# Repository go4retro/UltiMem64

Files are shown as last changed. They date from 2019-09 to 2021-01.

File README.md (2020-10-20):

# UltiMem64 

A 2 IC SRAM replacement for the Commodore 64 that offers all of the advantages of the VSP-fixed 64kB SRAM modules plus 2 megabytes of directly accessible RAM using a full featured memory management unit (MMU).

## Introduction

UltiMem64 replace the 2 4464 DRAM ICs on newer Commodore 64 motherboards (and can be installed in older 8-IC 4164 DRAM based motherboards using the DRAMCarrier PCB) and provides access to 2 megabytes of direct memory access (not REU access). The memory is instantly available when requested, no DMA needed.  The Color RAM IC installs in the 2114 space on motherboards containing a 2114 Color RAM and provides access to 64 kilobytes of Color memory nybbles.

## Technical Details

(*Although this information is currently correct, it may change based on developer feedback*)

The Commodore 64 64kB address space is partitioned into 16 4kB "pages", corresponding to the first nybble of a 16 bit address (the 'D' in $D0FF). The 2MB SRAM is likewise also partitioned into 4kB pages, which can then be mapped into any (or all) of the 16 slots in the MMU.

The MMU also supports the concept of a "mapping set", which means the developer can arrange up to 256 different 16 slot memory mappings, and choose any one of them at will.  Swapping out 64kB of RAM can take as little as 4 cycles (sta MAPPING_REG).

The system starts up in "hidden" mode, where the registers cannot be set or read from memory.  Reading some "magic addresses" will unhide the registers:

- $C0AA
- $C055
- $C0FF
- $C000
- $CO&lt;PAGE&gt;, where &lt;page&gt; is the high byte of the location where the registers should appear ($FF would place the registers at $ff00-)

Once the registers are visible, the are as follows:

| Register | Bit  | Note |
| --- | ---- | --- |
| BASE | 0 | MMU enabled |
| BASE+1 | 7:0  | MMU mapping "window" |
| BASE+2 | 7:0  | MMU mapping in use |
| BASE+3 | 6:0  | Color RAM 1kB mapping |
| BASE+10 to BASE+1F | 7:0  | Low bits of 16 MMU mappings (16 mappings)  |
| BASE+20 to BASE+2F | 7:0  | High bits of 16 MMU mappings (16 mappings) |

To map memory, set the mapping "window" to the set you wish to change, and then alter the data in values BASE+10 to BASE+2F.  To run the code in that mapping, set the value of the map usage register to the desired map number (0-255).

Currently, to hide the registers, simply read the magic memory locations again and set the <page> to be 0.

The MMU replaces the upper 4 bits of the 16 bit memory address with the 9 bits of data from the mapping registers, using the upper 4 bits as a 0-15 "index" into the mapping set (mapping 0 will be used for memory access in the $0XXX range, etc.).  When the MMU is off, only the first 64kB of the SRAM is visible.

Since any mapping can point to any 4kB space in the real address space, one can place the same memory bank in multiple locations in the address map (map $123C00 so it appears at $4C00 and $FC00) or other interesting combinations.

The Color RAM mapping is simpler, and is simply a 6 bit value that choose which of the 64 1kB Color RAM "pages" will be used for the Color RAM data. There is no way to set Color RAM without switching to that specific mapping, so it is best to populate/change Color RAM during video blanking periods.

## Future Directions:

- Expand SRAM to 8MB (Alliance offers an 8MB SRAM in the same footprint)
- Utilize top two bits of MMU mapping to set read/write and IRQ on write flags for any 5kB page.
- Support a way to set mapping set without unhiding all registers (like 128 does)
- Possibly support a way to support auto-incremented memory store/read.

## License
Copyright (C) 2019-20  RETRO Innovations

These files are free designs; you can redistribute them and/or modify
them under the terms of the Creative Commons Attribution-ShareAlike 
4.0 International License.

You should have received a copy of the license along with this
work. If not, see <http://creativecommons.org/licenses/by-sa/4.0/>.

These files are distributed in the hope that they will be useful,
but WITHOUT ANY WARRANTY; without even the implied warranty of
MERCHANTABILITY or FITNESS FOR A PARTICULAR PURPOSE.  See the
license for more details.

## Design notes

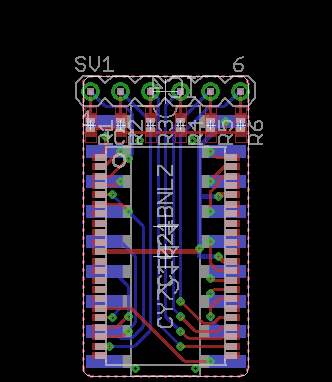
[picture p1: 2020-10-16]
pcb/UltiMem64_Color.png

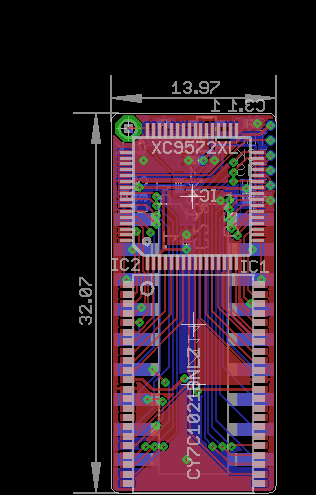
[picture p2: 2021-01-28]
pcb/UltiMEM64_Color PCB.png

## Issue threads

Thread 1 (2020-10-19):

Thoughts on memory expansion and MMU etc

gardners, 2020-10-19:
Hi Jim,

Nice project.  A couple of thoughts and ideas:

1. For the colour RAM, have you thought about having the colour RAM selection automatically change every raster line, so that you have a kind of "hardware FLI"?  You only need to use 8 of the 1K pages for this.

2. Much has been said about the upper-nybl of the colour RAM not being physically connected, and the last 24 bytes not being used, and thus might be candidate register locations. The later seems a sensible approach to me, but you will still want some kind of knock, so that routines that just fill all 4 pages of colour RAM don't cause problems.  Your four-step knock looks ok, if perhaps a little over-complex, in so far as the number of cycles required will be quite high.  Liveable, but just something worth keeping in mind.  If you are sniffing the bus, you could instead use one or more of the unintended NOP opcodes to do most of it.

Paul.

go4retro, 2020-10-19:
The Color RAM idea sounds cool, I'll consider it.

On the knock, concerning Color RAM, if I work the functionality into the 2114 SRAM replacement, I doubt I'd need the knock all the time.  Knock to turn it on, and then just leave it on (I'd assume the dev using the feature would just set the last 24 nybbles to 0, to ensure VSP code would look OK, and then switch the last 24 bytes to registers, and always use them (the design would need a flying lead to PHI0, since it'd need to know which accesses are CPU and which are VIC.  Robin Harbron asked that the design offer a way to configue a page of SRAM not currently in use, so the code could use one page for display while setting up a shadow copy for the next frame, wihtout having to wait until the end of the frame to do that.  To enable that type of features requires access to PHI0.

As for the main unit, I could use non standard NOPs, though if someones wants to support this MMU design on a 65C02 or 65C816-based upgrade, that would pose problems (existing code would fail on those newer units).  Thoughts?

gardners, 2020-10-19:
Agreed using the colour RAM 24 spare nybls for registers makes the most sense, I think.

As for the non-standard NOPs, you are right, that this won't be a solution for 65C02 or 65C816 processors, so it should be an optional mode of operation.

Meanwhile, I have an idea for another C64 add-on board, to help discover remaining VIC-II tricks if you are interested. Basically it is a cartridge that pulls DMA low, and interfaces to a host computer allowing the host computer to determine every memory access during each video frame. That is, you can say which registers get written at exactly which cycle of which raster line (and probably even do some horrible tricks with doing multiple accesses per cycle for the chips with async registers).  This would allow for rapidly exploring potential VIC-II tricks, without having to make C64 code that actually achieves that.  It would be up to the demo coders to then work out code that achieves those memory accesses in practice.

go4retro, 2020-10-20:
I am indeed interested.  What speed uC/host computer were you considering?  I know there's a RPi cart that interfaces that to the bus.

Jim

gardners, 2020-10-22:
Hi Jim,

I'd just use a cheap FPGA + USB serial interface. A MAX10 FPGA + JTAG USB serial adapter + level converters and buffers should be sufficient.  The FPGA can do the bus control, and has enough internal RAM to hold the info on every required memory access over a whole frame (~17K/21K cycles (NTSC/PAL) x (2 address bytes plus 1 data byte).  Power requirements would be low enough to be powered from the C64 expansion port.

Paul.

gardners, 2020-10-22:
... It could also double as a multipurpose cartridge emulator.

go4retro, 2020-10-23:
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
To save time, I was looking for a prebuilt module for the FPGA.  THis
one is so close, but only has 38 IO:

https://www.ebay.com/itm/STEP-MAX10-Intel-Altera-FPGA-development-board-/143318504573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

Jim

--
RETRO Innovations, Contemporary Gear for Classic Systems
www.go4retro.com
store.go4retro.com

gardners, 2020-10-23:
Going for a pre-built FPGA module to fit to a cheap adapter board would make sense, as I don't think the volume for this product would be particularly high. In that case, I would recommend going for a TE0725-03 from Trenz Electronic, who also make the MEGA65 mainboards.  I use the TE0725 in the MEGAphone and other projects, and am thus quite familiar with it. It has 104 IO available, which is more than enough.  We could copy the level converters etc from the MEGA65 main board schematic, and have a working thing pretty quickly.

Another funny approach would be to make an adapter that connects a MEGA65 to a C64 via the expansion port, and allows the same functions.

go4retro, 2020-10-24:
Dunno, that part is both overkill and also not enough for hobbyist use.  It requires a JTAG programmer, where the MAX10 board I linked has a built in programmer, so nothing else needed, and it's half the price.  With a cheap FR4 PCB with some simple level converters and this board, you're still below $50.00 in costs, whereas the other option is significantly more.  I realize it is not a huge demand board, but I think the USB programming and the half price point would allow it to be the basis for many more projects.

I think I'd rather find a way to deal with the 2 missing signals, the price point is much better.

Jim

gardners, 2020-10-24:
Understood. So, in terms of signals, you need to be able to write A0-15 and D0-7 = 24 lines. Then you need to be able to tri-state those = +1 signal. Then you probably want to monitor /BA, and be able to pull /DMA low, so +2 signals.  That still is only 27 signals. You in fact then have enough for separately tri-stating D0-7 and being able to drive them: +9 signals = 36 signals.  I guess you also want /RESET so that it can be used to reset the machine +1 = 37. Then you can monitor either /EXROM or /GAME, but not both, to use up the last pin in your 38-pin budget.

But if you are willing to consider a full custom PCB, you can use a MAX10 and get lots more spare pins.

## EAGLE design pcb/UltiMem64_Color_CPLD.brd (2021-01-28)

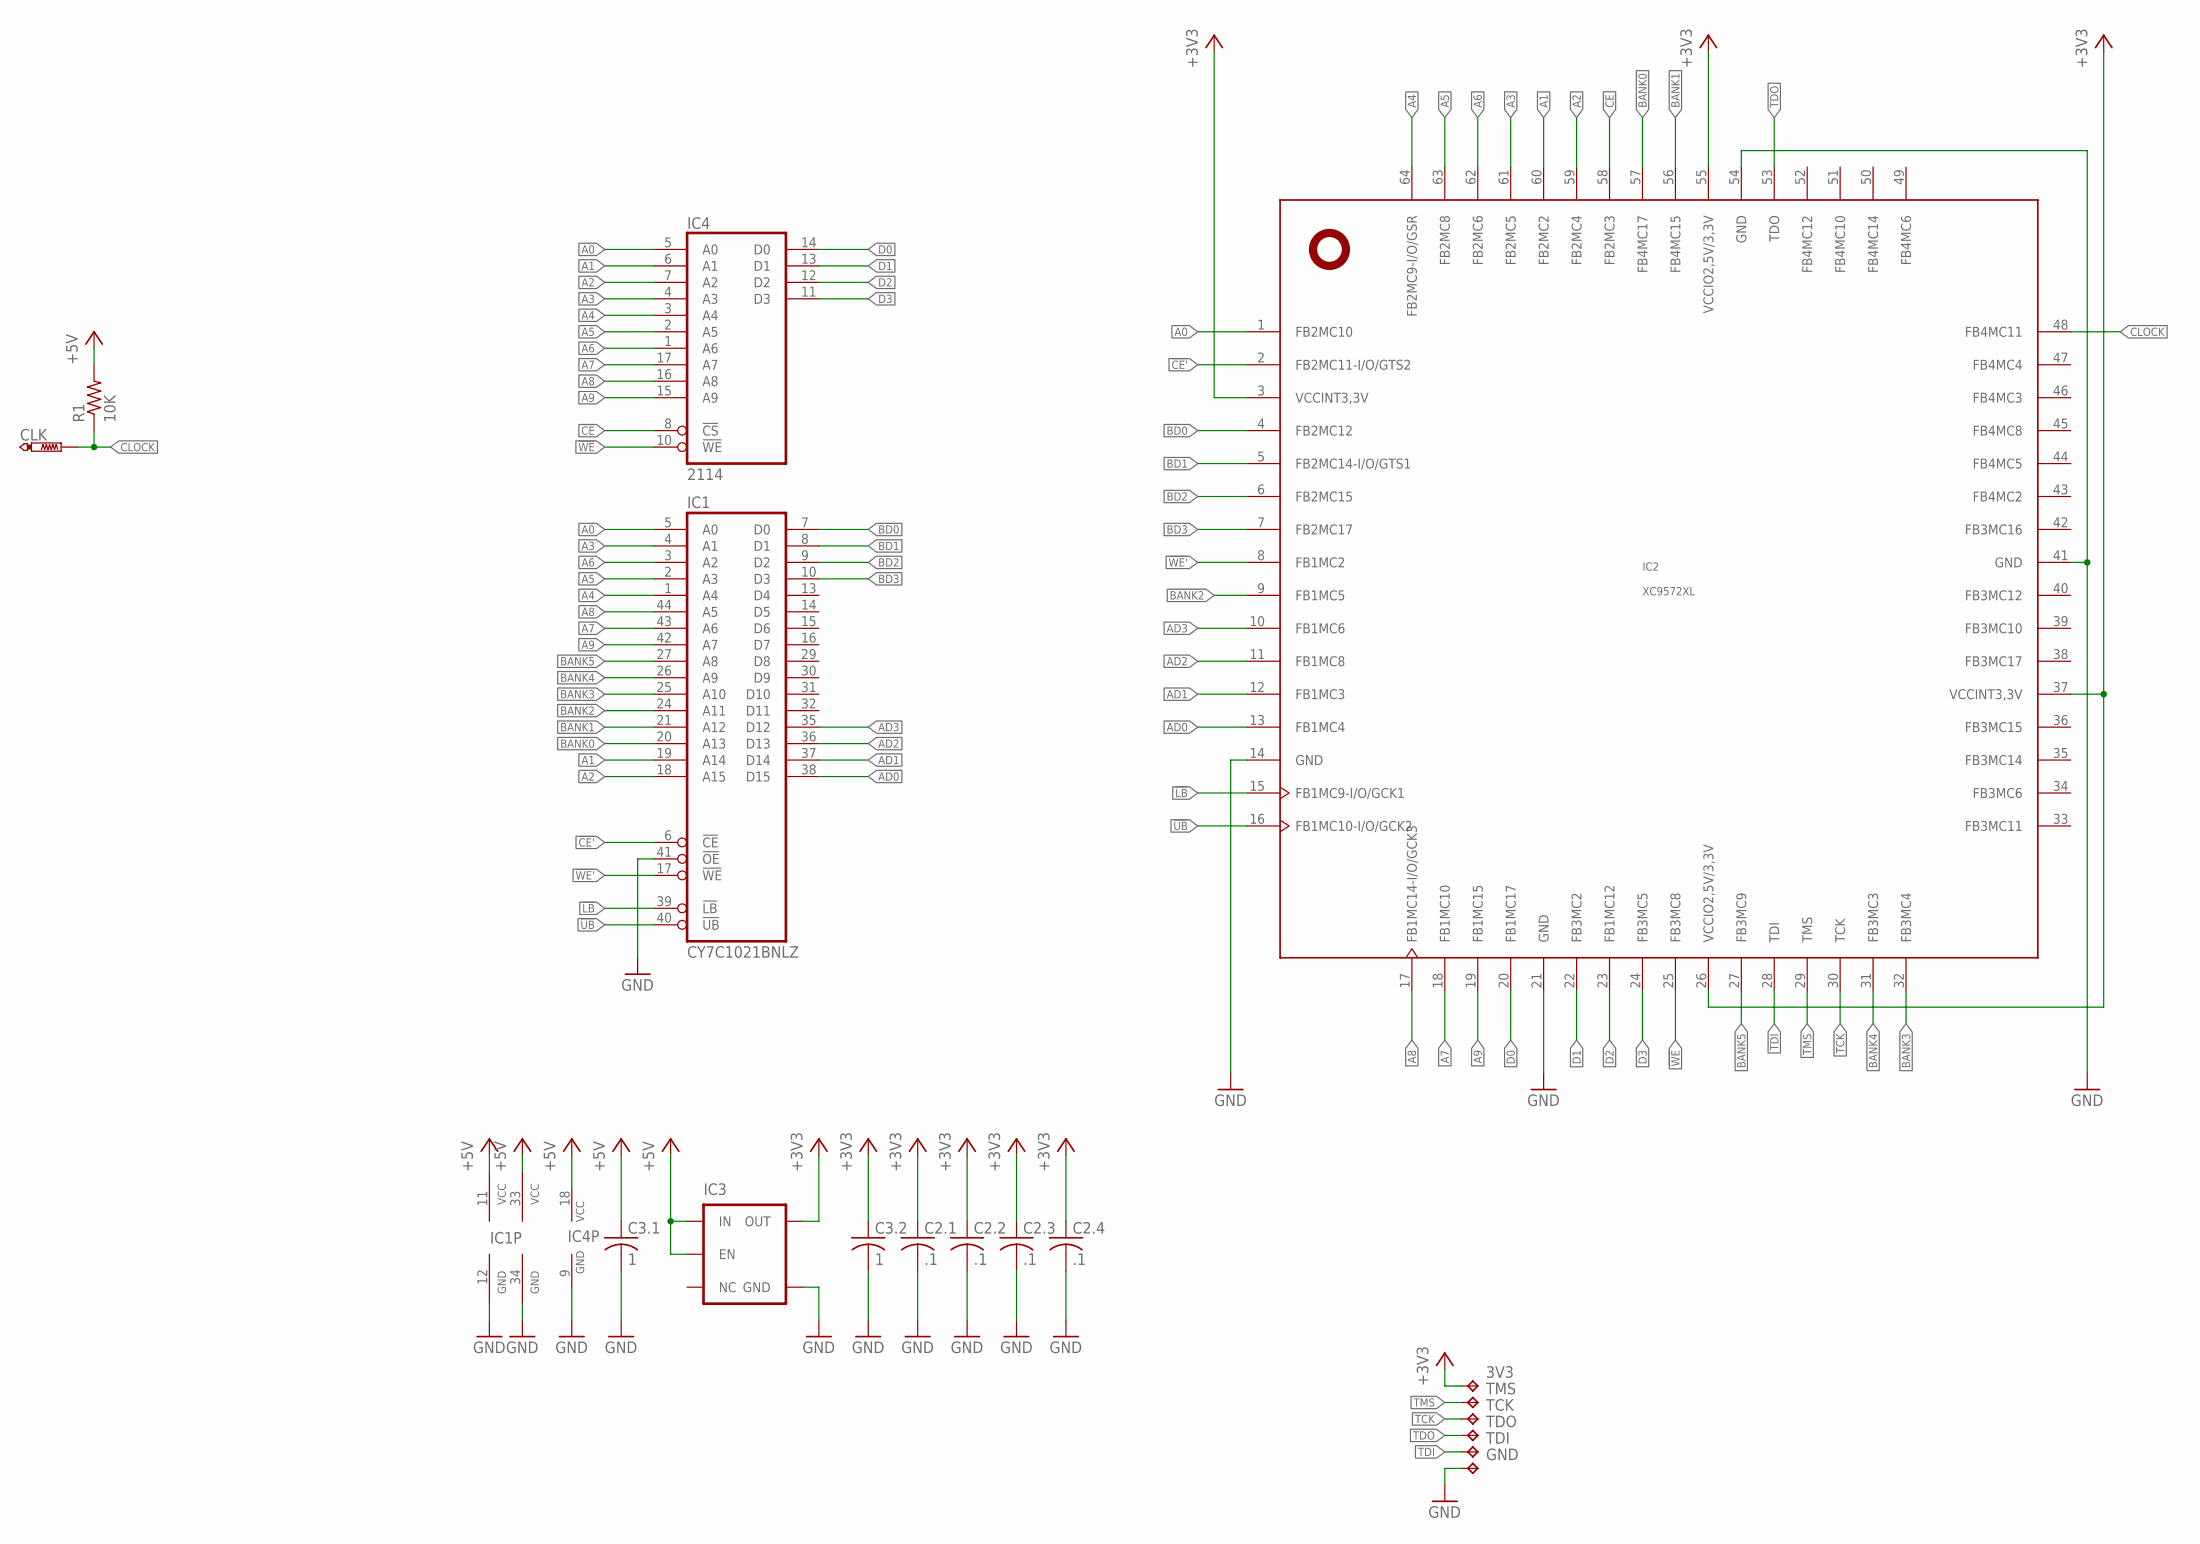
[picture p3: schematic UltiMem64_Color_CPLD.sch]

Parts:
3V3: TPTP09R; TP09R
C2.1, C2.2, C2.3, C2.4: .1; C0402
C3.1, C3.2: 1; C0402
CLK: PTR1PAD1-13; P1-13
GND: TPTP09R; TP09R
IC1: CY7C1021BNLZ; TSOP44-II
IC2: XC9572XL; VQFP64
IC3: V_REG_TPS76433SOT23-5; SOT23-5
IC4: 2114; DIL18-SMD-REVERSE
R1: 10K; R0402
TCK: TPTP09R; TP09R
TDI: TPTP09R; TP09R
TDO: TPTP09R; TP09R
TMS: TPTP09R; TP09R

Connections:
!CE: IC2.58 (FB2MC3), IC4.8 (!CS)
!CE': IC1.6 (!CE), IC2.2 (FB2MC11-I/O/GTS2)
!LB: IC1.39 (!LB), IC2.15 (FB1MC9-I/O/GCK1)
!UB: IC1.40 (!UB), IC2.16 (FB1MC10-I/O/GCK2)
!WE: IC2.25 (FB3MC8), IC4.10 (!WE)
!WE': IC1.17 (!WE), IC2.8 (FB1MC2)
+3V3: 3V3.TP, C2.1.1, C2.2.1, C2.3.1, C2.4.1, C3.2.1, IC2.3 (VCCINT3,3V), IC2.26 (VCCIO2,5V/3,3V), IC2.37 (VCCINT3,3V), IC2.55 (VCCIO2,5V/3,3V), IC3.5 (OUT)
+5V: C3.1.1, IC1.11 (VCC), IC1.33 (VCC), IC3.1 (IN), IC3.3 (EN), IC4.18 (VCC), R1.2
A0: IC1.5 (A0), IC2.1 (FB2MC10), IC4.5 (A0)
A1: IC1.19 (A14), IC2.60 (FB2MC2), IC4.6 (A1)
A2: IC1.18 (A15), IC2.59 (FB2MC4), IC4.7 (A2)
A3: IC1.4 (A1), IC2.61 (FB2MC5), IC4.4 (A3)
A4: IC1.1 (A4), IC2.64 (FB2MC9-I/O/GSR), IC4.3 (A4)
A5: IC1.2 (A3), IC2.63 (FB2MC8), IC4.2 (A5)
A6: IC1.3 (A2), IC2.62 (FB2MC6), IC4.1 (A6)
A7: IC1.43 (A6), IC2.18 (FB1MC10), IC4.17 (A7)
A8: IC1.44 (A5), IC2.17 (FB1MC14-I/O/GCK3), IC4.16 (A8)
A9: IC1.42 (A7), IC2.19 (FB1MC15), IC4.15 (A9)
AD0: IC1.38 (D15), IC2.13 (FB1MC4)
AD1: IC1.37 (D14), IC2.12 (FB1MC3)
AD2: IC1.36 (D13), IC2.11 (FB1MC8)
AD3: IC1.35 (D12), IC2.10 (FB1MC6)
BANK0: IC1.20 (A13), IC2.57 (FB4MC17)
BANK1: IC1.21 (A12), IC2.56 (FB4MC15)
BANK2: IC1.24 (A11), IC2.9 (FB1MC5)
BANK3: IC1.25 (A10), IC2.32 (FB3MC4)
BANK4: IC1.26 (A9), IC2.31 (FB3MC3)
BANK5: IC1.27 (A8), IC2.27 (FB3MC9)
BD0: IC1.7 (D0), IC2.4 (FB2MC12)
BD1: IC1.8 (D1), IC2.5 (FB2MC14-I/O/GTS1)
BD2: IC1.9 (D2), IC2.6 (FB2MC15)
BD3: IC1.10 (D3), IC2.7 (FB2MC17)
CLOCK: CLK.TP, IC2.48 (FB4MC11), R1.1
D0: IC2.20 (FB1MC17), IC4.14 (D0)
D1: IC2.22 (FB3MC2), IC4.13 (D1)
D2: IC2.23 (FB1MC12), IC4.12 (D2)
D3: IC2.24 (FB3MC5), IC4.11 (D3)
GND: C2.1.2, C2.2.2, C2.3.2, C2.4.2, C3.1.2, C3.2.2, GND.TP, IC1.12 (GND), IC1.34 (GND), IC1.41 (!OE), IC2.14 (GND), IC2.21 (GND), IC2.41 (GND), IC2.54 (GND), IC3.2 (GND), IC4.9 (GND)
TCK: IC2.30 (TCK), TCK.TP
TDI: IC2.28 (TDI), TDI.TP
TDO: IC2.53 (TDO), TDO.TP
TMS: IC2.29 (TMS), TMS.TP

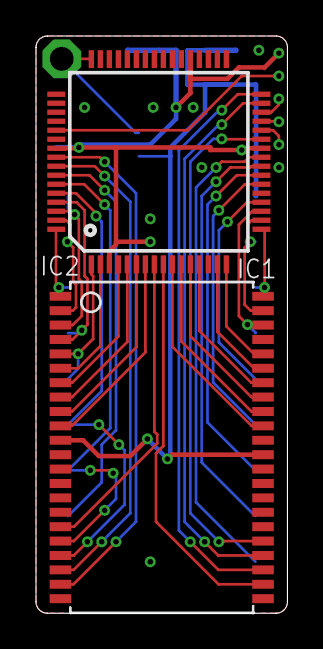
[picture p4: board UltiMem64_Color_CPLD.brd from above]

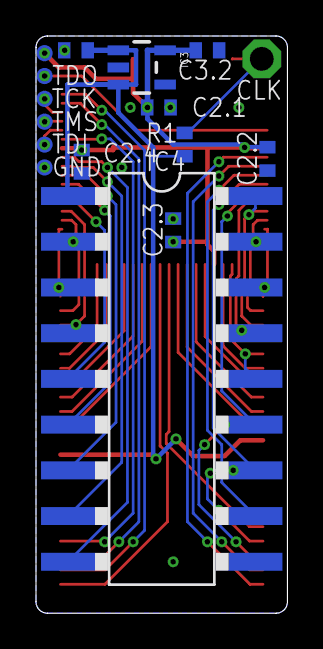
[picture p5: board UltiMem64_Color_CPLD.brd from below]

Board: 2 copper layers, 14.0 x 32.1 mm, 18 parts (15 on the bottom side), 42 nets.

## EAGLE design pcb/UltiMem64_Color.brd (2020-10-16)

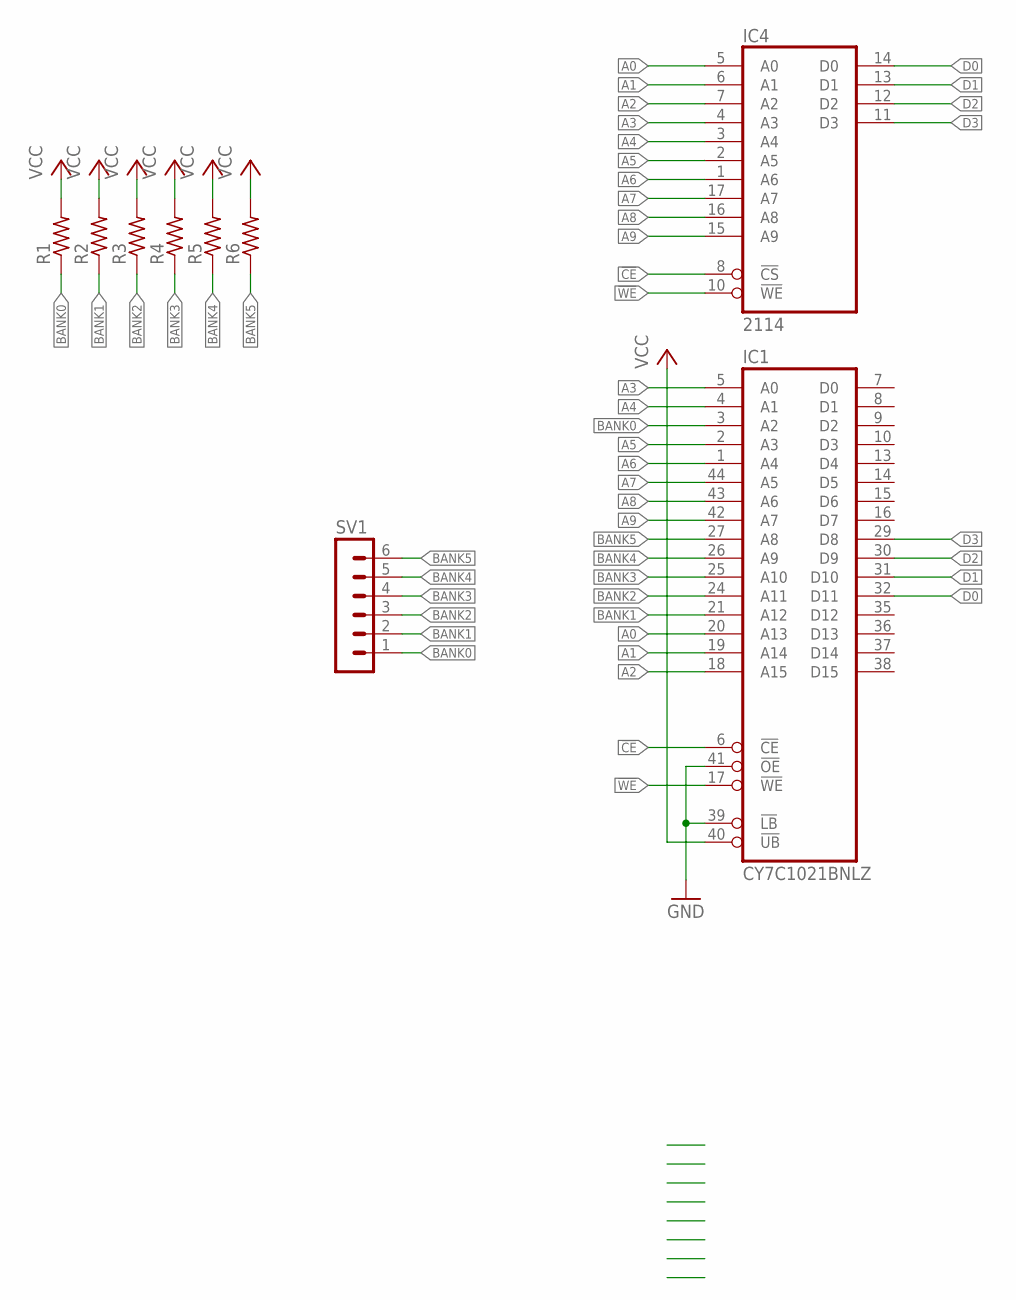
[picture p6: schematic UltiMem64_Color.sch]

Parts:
IC1: CY7C1021BNLZ; TSOP44-II
IC4: 2114; DIL18-SMD-REVERSE
R1, R2, R3, R4, R5, R6: R-US_R0402; R0402
SV1: MA06-1

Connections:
!CE: IC1.6 (!CE), IC4.8 (!CS)
!WE: IC1.17 (!WE), IC4.10 (!WE)
A0: IC1.20 (A13), IC4.5 (A0)
A1: IC1.19 (A14), IC4.6 (A1)
A2: IC1.18 (A15), IC4.7 (A2)
A3: IC1.5 (A0), IC4.4 (A3)
A4: IC1.4 (A1), IC4.3 (A4)
A5: IC1.2 (A3), IC4.2 (A5)
A6: IC1.1 (A4), IC4.1 (A6)
A7: IC1.44 (A5), IC4.17 (A7)
A8: IC1.43 (A6), IC4.16 (A8)
A9: IC1.42 (A7), IC4.15 (A9)
BANK0: IC1.3 (A2), R1.1, SV1.1
BANK1: IC1.21 (A12), R2.1, SV1.2
BANK2: IC1.24 (A11), R3.1, SV1.3
BANK3: IC1.25 (A10), R4.1, SV1.4
BANK4: IC1.26 (A9), R5.1, SV1.5
BANK5: IC1.27 (A8), R6.1, SV1.6
D0: IC1.32 (D11), IC4.14 (D0)
D1: IC1.31 (D10), IC4.13 (D1)
D2: IC1.30 (D9), IC4.12 (D2)
D3: IC1.29 (D8), IC4.11 (D3)
GND: IC1.12 (GND), IC1.34 (GND), IC1.39 (!LB), IC1.41 (!OE), IC4.9 (GND)
VCC: IC1.11 (VCC), IC1.33 (VCC), IC1.40 (!UB), IC4.18 (VCC), R1.2, R2.2, R3.2, R4.2, R5.2, R6.2

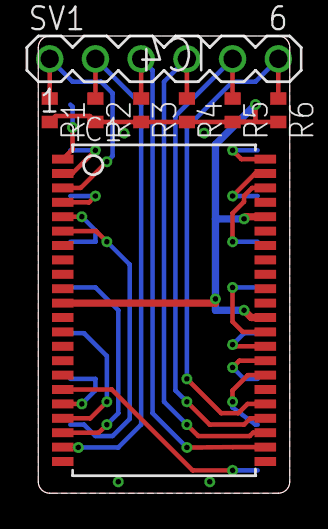
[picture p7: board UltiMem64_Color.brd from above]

Board: 2 copper layers, 14.0 x 25.4 mm, 9 parts (0 on the bottom side), 24 nets.

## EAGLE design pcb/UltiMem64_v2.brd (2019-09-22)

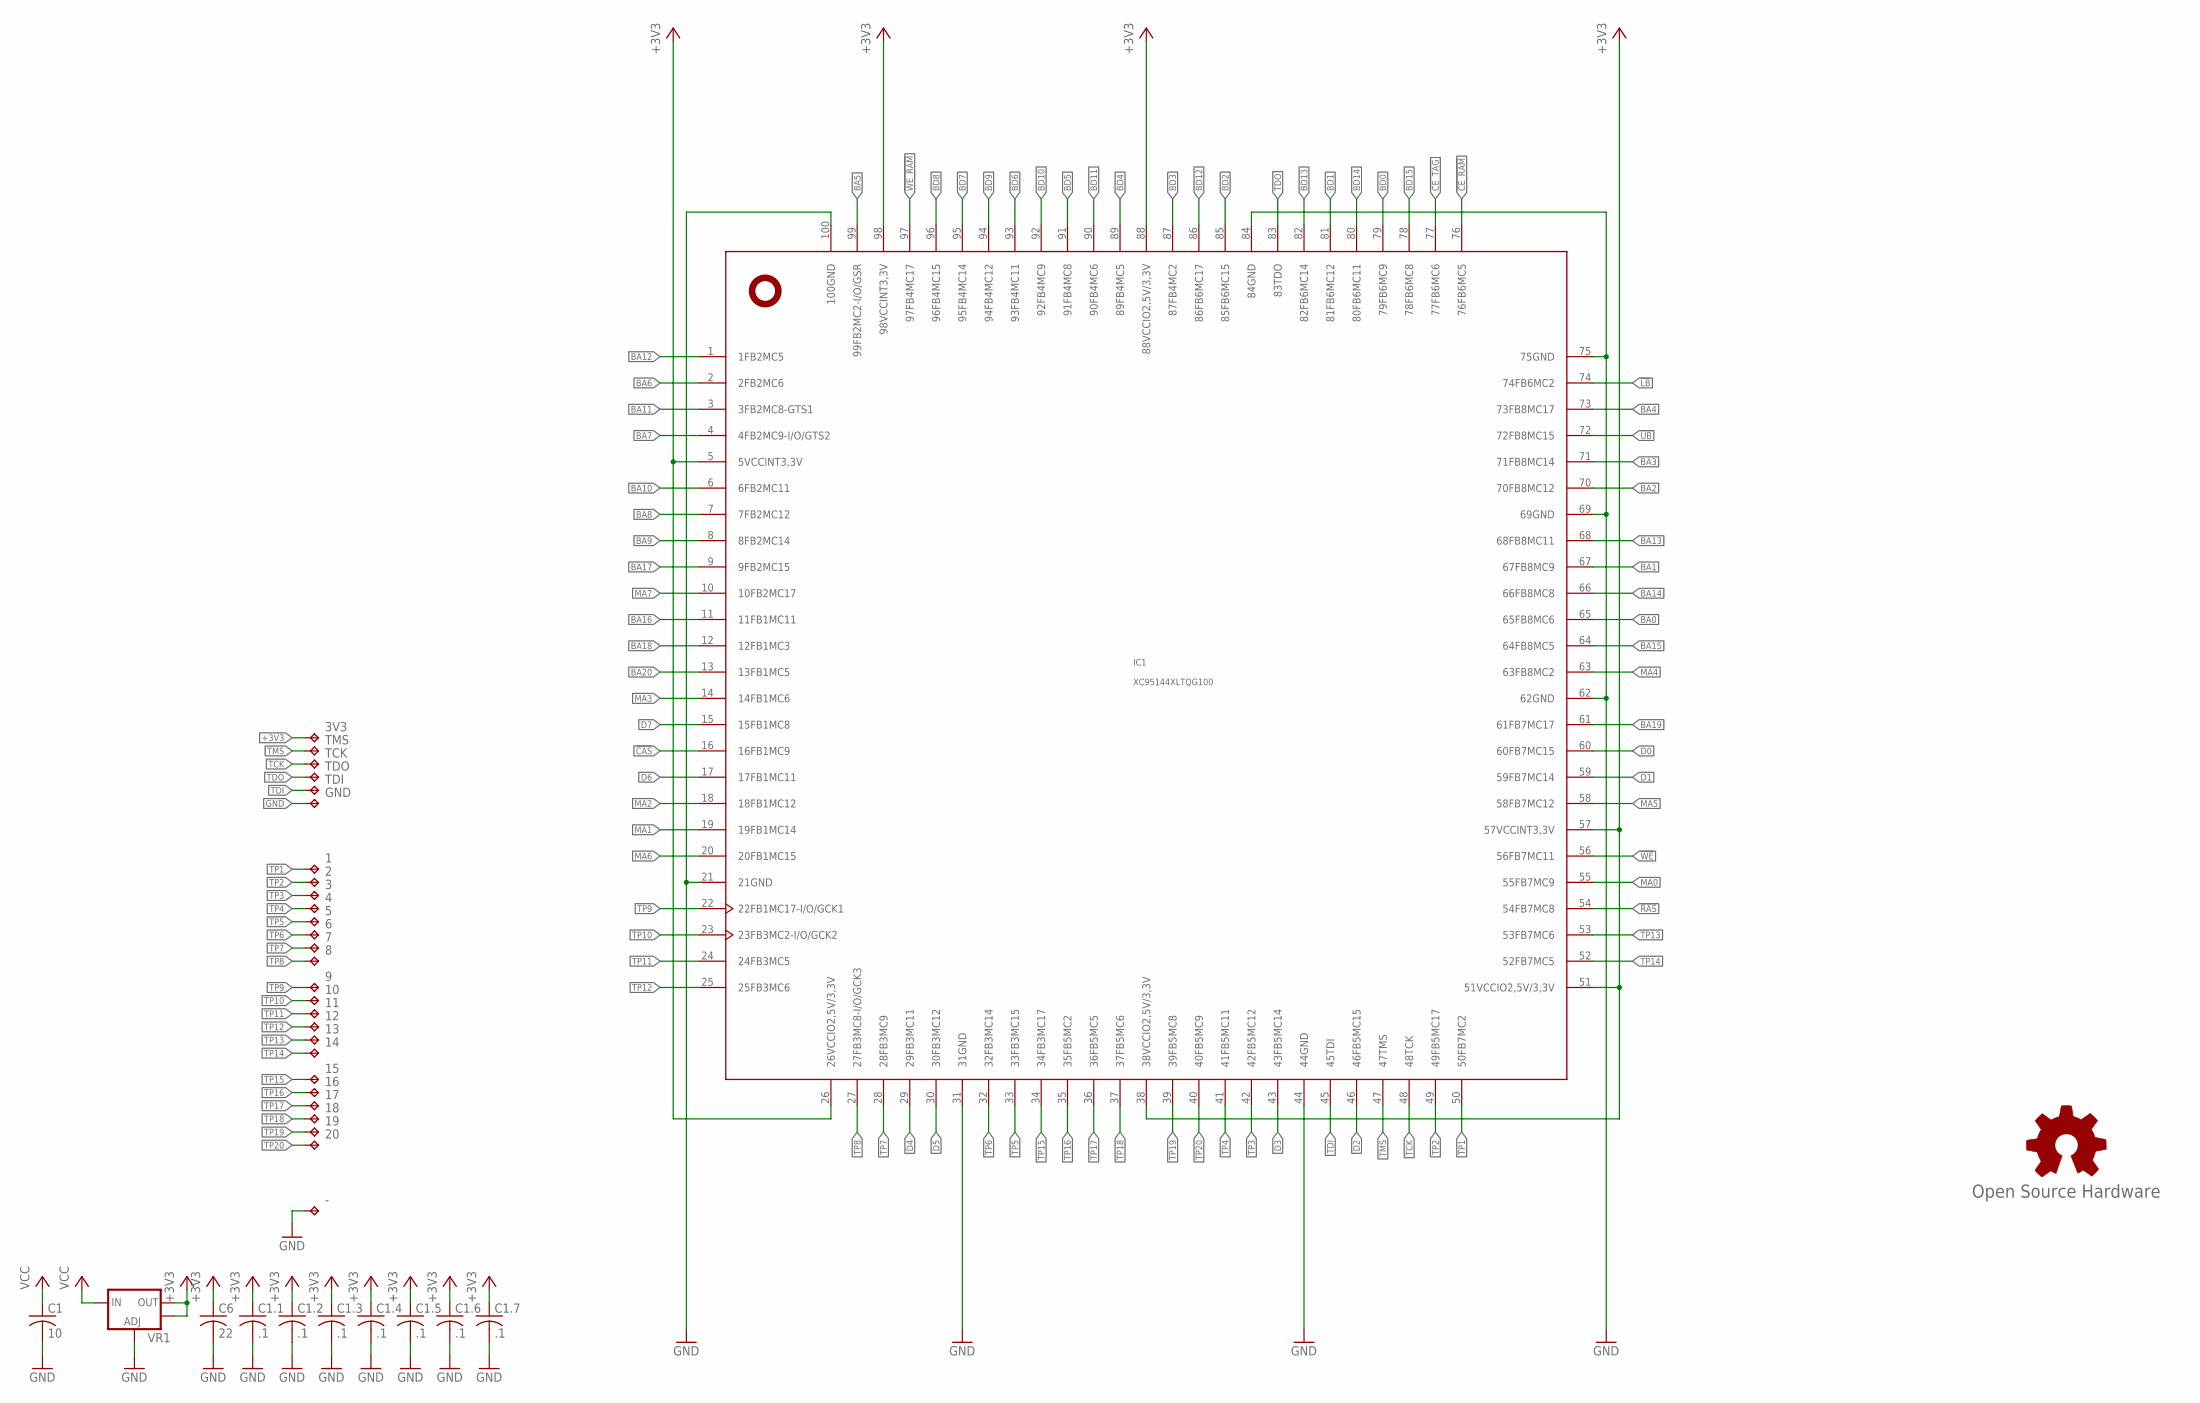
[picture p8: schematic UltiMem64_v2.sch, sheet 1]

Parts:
1, 2, 3, 4, 5, 6, 7, 8, 9, 10, 11, 12, 13, 14: TPPAD1-13; P1-13
3V3: TPTP09R; TP09R
15, 16, 17, 18, 19, 20: TPTP08R; TP08R
-: TPPAD1-13; P1-13
C1: 10; C0805
C1.1, C1.2, C1.3, C1.4, C1.5, C1.6, C1.7: .1; C0402
C6: 22; C0805
GND: TPTP10R; TP10R
GOLD_ORB_SM1: Open Source Hardware; OSHW_5MM
IC1: XC95144XLTQG100; TQFP100
TCK: TPTP09R; TP09R
TDI: TPTP09R; TP09R
TDO: TPTP09R; TP09R
TMS: TPTP09R; TP09R
VR1: V_REG_LM1117SOT223; SOT223

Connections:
!CAS: IC1.16 (16FB1MC9); also elsewhere on the board
!CE_RAM: IC1.76 (76FB6MC5); also elsewhere on the board
!CE_TAG: IC1.77 (77FB6MC6); also elsewhere on the board
!LB: IC1.74 (74FB6MC2); also elsewhere on the board
!RAS: IC1.54 (54FB7MC8); also elsewhere on the board
!UB: IC1.72 (72FB8MC15); also elsewhere on the board
!WE: IC1.56 (56FB7MC11); also elsewhere on the board
!WE_RAM: IC1.97 (97FB4MC17); also elsewhere on the board
+3V3: 3V3.TP, C1.1.1, C1.2.1, C1.3.1, C1.4.1, C1.5.1, C1.6.1, C1.7.1, C6.1, IC1.5 (5VCCINT3,3V), IC1.26 (26VCCIO2,5V/3,3V), IC1.38 (38VCCIO2,5V/3,3V), IC1.51 (51VCCIO2,5V/3,3V), IC1.57 (57VCCINT3,3V), IC1.88 (88VCCIO2,5V/3,3V), IC1.98 (98VCCINT3,3V), VR1.2 (OUT), VR1.4 (OUT); also elsewhere on the board
BA0: IC1.65 (65FB8MC6); also elsewhere on the board
BA1: IC1.67 (67FB8MC9); also elsewhere on the board
BA2: IC1.70 (70FB8MC12); also elsewhere on the board
BA3: IC1.71 (71FB8MC14); also elsewhere on the board
BA4: IC1.73 (73FB8MC17); also elsewhere on the board
BA5: IC1.99 (99FB2MC2-I/O/GSR); also elsewhere on the board
BA6: IC1.2 (2FB2MC6); also elsewhere on the board
BA7: IC1.4 (4FB2MC9-I/O/GTS2); also elsewhere on the board
BA8: IC1.7 (7FB2MC12); also elsewhere on the board
BA9: IC1.8 (8FB2MC14); also elsewhere on the board
BA10: IC1.6 (6FB2MC11); also elsewhere on the board
BA11: IC1.3 (3FB2MC8-GTS1); also elsewhere on the board
BA12: IC1.1 (1FB2MC5); also elsewhere on the board
BA13: IC1.68 (68FB8MC11); also elsewhere on the board
BA14: IC1.66 (66FB8MC8); also elsewhere on the board
BA15: IC1.64 (64FB8MC5); also elsewhere on the board
BA16: IC1.11 (11FB1MC11); also elsewhere on the board
BA17: IC1.9 (9FB2MC15); also elsewhere on the board
BA18: IC1.12 (12FB1MC3); also elsewhere on the board
BA19: IC1.61 (61FB7MC17); also elsewhere on the board
BA20: IC1.13 (13FB1MC5); also elsewhere on the board
BD0: IC1.79 (79FB6MC9); also elsewhere on the board
BD1: IC1.81 (81FB6MC12); also elsewhere on the board
BD2: IC1.85 (85FB6MC15); also elsewhere on the board
BD3: IC1.87 (87FB4MC2); also elsewhere on the board
BD4: IC1.89 (89FB4MC5); also elsewhere on the board
BD5: IC1.91 (91FB4MC8); also elsewhere on the board
BD6: IC1.93 (93FB4MC11); also elsewhere on the board
BD7: IC1.95 (95FB4MC14); also elsewhere on the board
BD8: IC1.96 (96FB4MC15); also elsewhere on the board
BD9: IC1.94 (94FB4MC12); also elsewhere on the board
BD10: IC1.92 (92FB4MC9); also elsewhere on the board
BD11: IC1.90 (90FB4MC6); also elsewhere on the board
BD12: IC1.86 (86FB6MC17); also elsewhere on the board
BD13: IC1.82 (82FB6MC14); also elsewhere on the board
BD14: IC1.80 (80FB6MC11); also elsewhere on the board
BD15: IC1.78 (78FB6MC8); also elsewhere on the board
D0: IC1.60 (60FB7MC15); also elsewhere on the board
D1: IC1.59 (59FB7MC14); also elsewhere on the board
D2: IC1.46 (46FB5MC15); also elsewhere on the board
D3: IC1.43 (43FB5MC14); also elsewhere on the board
D4: IC1.29 (29FB3MC11); also elsewhere on the board
D5: IC1.30 (30FB3MC12); also elsewhere on the board
D6: IC1.17 (17FB1MC11); also elsewhere on the board
D7: IC1.15 (15FB1MC8); also elsewhere on the board
GND: -.TP, C1.2, C1.1.2, C1.2.2, C1.3.2, C1.4.2, C1.5.2, C1.6.2, C1.7.2, C6.2, GND.TP, IC1.21 (21GND), IC1.31 (31GND), IC1.44 (44GND), IC1.62 (62GND), IC1.69 (69GND), IC1.75 (75GND), IC1.84 (84GND), IC1.100 (100GND), VR1.1 (ADJ); also elsewhere on the board
MA0: IC1.55 (55FB7MC9); also elsewhere on the board
MA1: IC1.19 (19FB1MC14); also elsewhere on the board
MA2: IC1.18 (18FB1MC12); also elsewhere on the board
MA3: IC1.14 (14FB1MC6); also elsewhere on the board
MA4: IC1.63 (63FB8MC2); also elsewhere on the board
MA5: IC1.58 (58FB7MC12); also elsewhere on the board
MA6: IC1.20 (20FB1MC15); also elsewhere on the board
MA7: IC1.10 (10FB2MC17); also elsewhere on the board
TCK: IC1.48 (48TCK), TCK.TP
TDI: IC1.45 (45TDI), TDI.TP
TDO: IC1.83 (83TDO), TDO.TP
TMS: IC1.47 (47TMS), TMS.TP
TP1: 1.TP, IC1.50 (50FB7MC2)
TP2: 2.TP, IC1.49 (49FB5MC17)
TP3: 3.TP, IC1.42 (42FB5MC12)
TP4: 4.TP, IC1.41 (41FB5MC11)
TP5: 5.TP, IC1.33 (33FB3MC15)
TP6: 6.TP, IC1.32 (32FB3MC14)
TP7: 7.TP, IC1.28 (28FB3MC9)
TP8: 8.TP, IC1.27 (27FB3MC8-I/O/GCK3)
TP9: 9.TP, IC1.22 (22FB1MC17-I/O/GCK1)
TP10: 10.TP, IC1.23 (23FB3MC2-I/O/GCK2)
TP11: 11.TP, IC1.24 (24FB3MC5)
TP12: 12.TP, IC1.25 (25FB3MC6)
TP13: 13.TP, IC1.53 (53FB7MC6)
TP14: 14.TP, IC1.52 (52FB7MC5)
TP15: 15.TP, IC1.34 (34FB3MC17)
TP16: 16.TP, IC1.35 (35FB5MC2)
TP17: 17.TP, IC1.36 (36FB5MC5)
TP18: 18.TP, IC1.37 (37FB5MC6)
TP19: 19.TP, IC1.39 (39FB5MC8)
TP20: 20.TP, IC1.40 (40FB5MC9)
VCC: C1.1, VR1.3 (IN); also elsewhere on the board

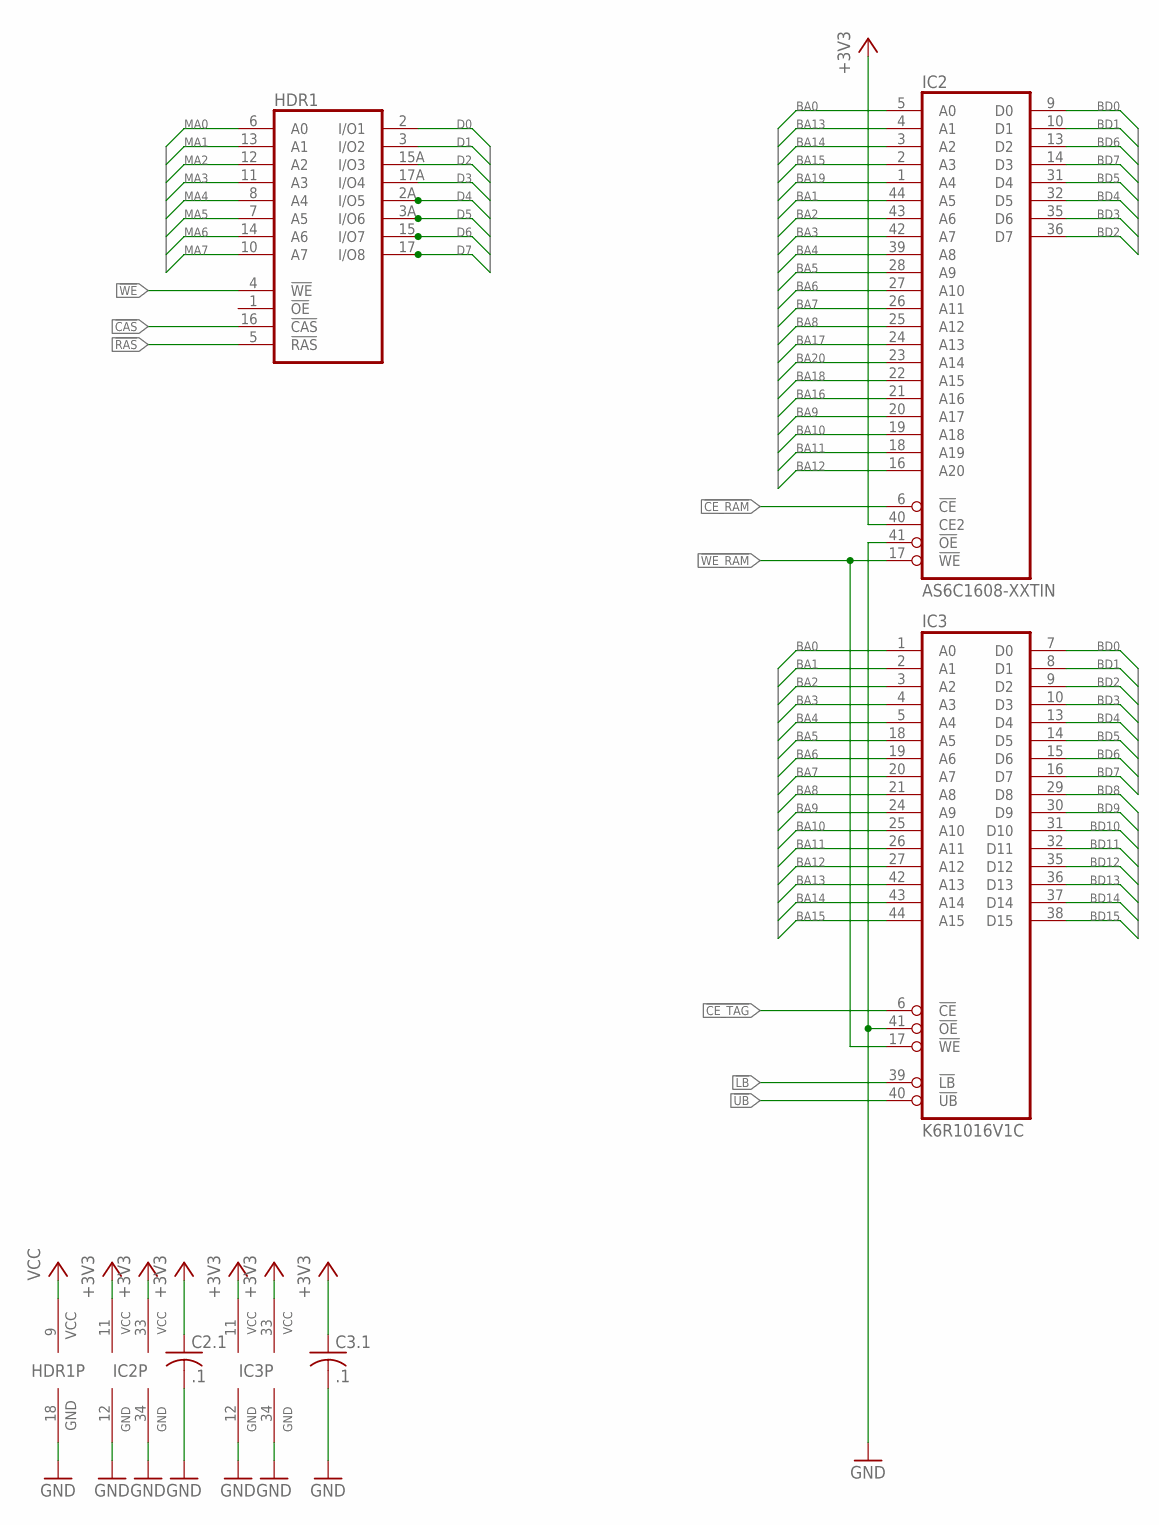
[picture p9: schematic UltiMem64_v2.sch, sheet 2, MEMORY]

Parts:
C2.1, C3.1: .1; C0402
HDR1: 2X41464C-HDR; 2XDIL18_REV
IC2: AS6C1608-XXTIN; TSOP44-II
IC3: K6R1016V1C; SOJ44/4

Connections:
!CAS: HDR1.16 (!CAS); also elsewhere on the board
!CE_RAM: IC2.6 (!CE); also elsewhere on the board
!CE_TAG: IC3.6 (!CE); also elsewhere on the board
!LB: IC3.39 (!LB); also elsewhere on the board
!RAS: HDR1.5 (!RAS); also elsewhere on the board
!UB: IC3.40 (!UB); also elsewhere on the board
!WE: HDR1.4 (!WE); also elsewhere on the board
!WE_RAM: IC2.17 (!WE), IC3.17 (!WE); also elsewhere on the board
+3V3: C2.1.1, C3.1.1, IC2.11 (VCC), IC2.33 (VCC), IC2.40 (CE2), IC3.11 (VCC), IC3.33 (VCC); also elsewhere on the board
BA0: IC2.5 (A0), IC3.1 (A0); also elsewhere on the board
BA1: IC2.44 (A5), IC3.2 (A1); also elsewhere on the board
BA2: IC2.43 (A6), IC3.3 (A2); also elsewhere on the board
BA3: IC2.42 (A7), IC3.4 (A3); also elsewhere on the board
BA4: IC2.39 (A8), IC3.5 (A4); also elsewhere on the board
BA5: IC2.28 (A9), IC3.18 (A5); also elsewhere on the board
BA6: IC2.27 (A10), IC3.19 (A6); also elsewhere on the board
BA7: IC2.26 (A11), IC3.20 (A7); also elsewhere on the board
BA8: IC2.25 (A12), IC3.21 (A8); also elsewhere on the board
BA9: IC2.20 (A17), IC3.24 (A9); also elsewhere on the board
BA10: IC2.19 (A18), IC3.25 (A10); also elsewhere on the board
BA11: IC2.18 (A19), IC3.26 (A11); also elsewhere on the board
BA12: IC2.16 (A20), IC3.27 (A12); also elsewhere on the board
BA13: IC2.4 (A1), IC3.42 (A13); also elsewhere on the board
BA14: IC2.3 (A2), IC3.43 (A14); also elsewhere on the board
BA15: IC2.2 (A3), IC3.44 (A15); also elsewhere on the board
BA16: IC2.21 (A16); also elsewhere on the board
BA17: IC2.24 (A13); also elsewhere on the board
BA18: IC2.22 (A15); also elsewhere on the board
BA19: IC2.1 (A4); also elsewhere on the board
BA20: IC2.23 (A14); also elsewhere on the board
BD0: IC2.9 (D0), IC3.7 (D0); also elsewhere on the board
BD1: IC2.10 (D1), IC3.8 (D1); also elsewhere on the board
BD2: IC2.36 (D7), IC3.9 (D2); also elsewhere on the board
BD3: IC2.35 (D6), IC3.10 (D3); also elsewhere on the board
BD4: IC2.32 (D5), IC3.13 (D4); also elsewhere on the board
BD5: IC2.31 (D4), IC3.14 (D5); also elsewhere on the board
BD6: IC2.13 (D2), IC3.15 (D6); also elsewhere on the board
BD7: IC2.14 (D3), IC3.16 (D7); also elsewhere on the board
BD8: IC3.29 (D8); also elsewhere on the board
BD9: IC3.30 (D9); also elsewhere on the board
BD10: IC3.31 (D10); also elsewhere on the board
BD11: IC3.32 (D11); also elsewhere on the board
BD12: IC3.35 (D12); also elsewhere on the board
BD13: IC3.36 (D13); also elsewhere on the board
BD14: IC3.37 (D14); also elsewhere on the board
BD15: IC3.38 (D15); also elsewhere on the board
D0: HDR1.2 (I/O1); also elsewhere on the board
D1: HDR1.3 (I/O2); also elsewhere on the board
D2: HDR1.15A (I/O3); also elsewhere on the board
D3: HDR1.17A (I/O4); also elsewhere on the board
D4: HDR1.2A (I/O5); also elsewhere on the board
D5: HDR1.3A (I/O6); also elsewhere on the board
D6: HDR1.15 (I/O7); also elsewhere on the board
D7: HDR1.17 (I/O8); also elsewhere on the board
GND: C2.1.2, C3.1.2, HDR1.18 (GND), IC2.12 (GND), IC2.34 (GND), IC2.41 (!OE), IC3.12 (GND), IC3.34 (GND), IC3.41 (!OE); also elsewhere on the board
MA0: HDR1.6 (A0); also elsewhere on the board
MA1: HDR1.13 (A1); also elsewhere on the board
MA2: HDR1.12 (A2); also elsewhere on the board
MA3: HDR1.11 (A3); also elsewhere on the board
MA4: HDR1.8 (A4); also elsewhere on the board
MA5: HDR1.7 (A5); also elsewhere on the board
MA6: HDR1.14 (A6); also elsewhere on the board
MA7: HDR1.10 (A7); also elsewhere on the board
VCC: HDR1.9 (VCC); also elsewhere on the board

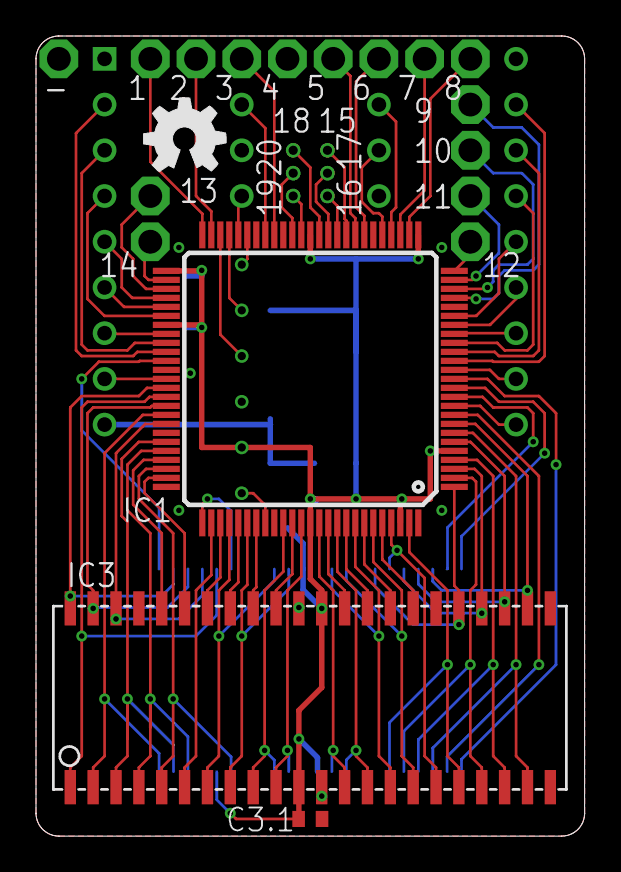
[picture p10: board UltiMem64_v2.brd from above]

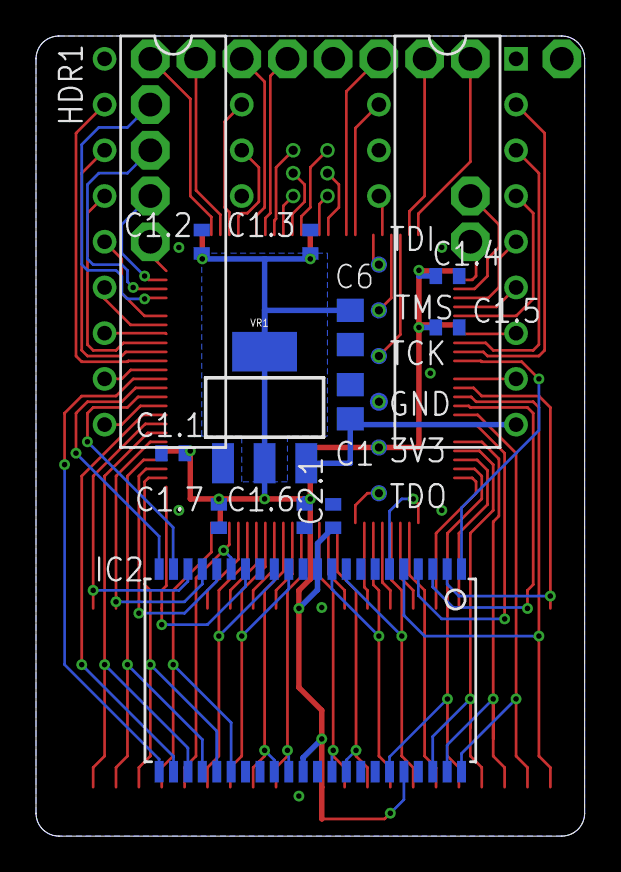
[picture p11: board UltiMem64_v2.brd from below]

Board: 2 copper layers, 30.5 x 44.5 mm, 44 parts (18 on the bottom side), 88 nets.

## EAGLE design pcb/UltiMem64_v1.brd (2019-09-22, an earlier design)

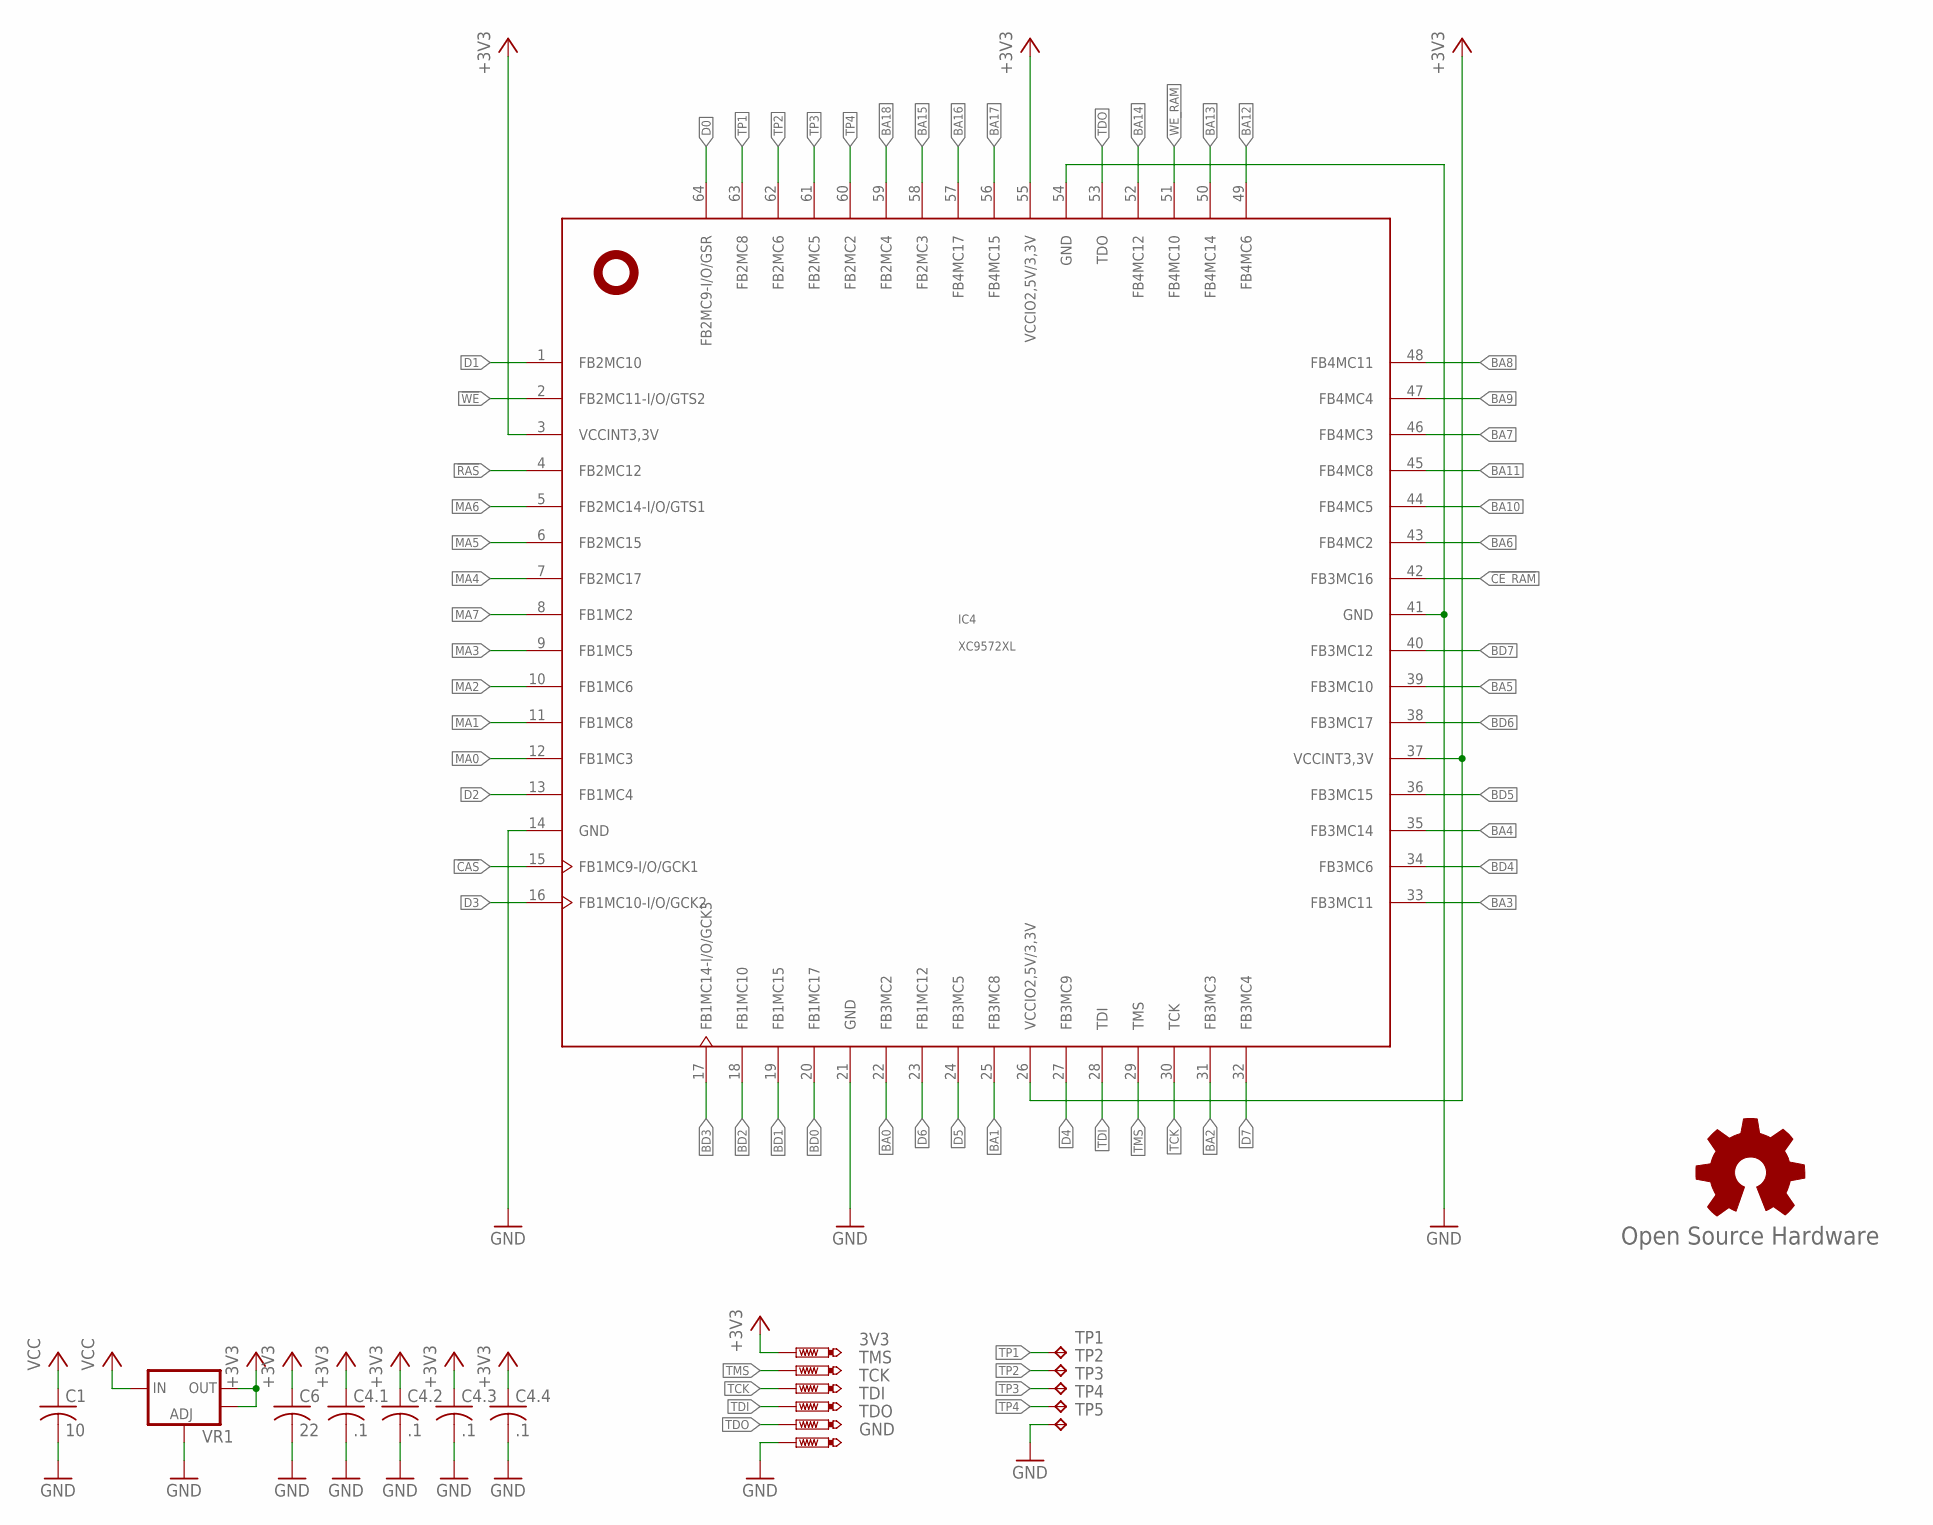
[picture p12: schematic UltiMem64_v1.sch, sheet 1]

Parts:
3V3: PTR1TP08R; TP08R
C1: 10; C0805
C4.1, C4.2, C4.3, C4.4: .1; C0402
C6: 22; C0805
GND: PTR1TP08R; TP08R
GOLD_ORB_SM1: Open Source Hardware; OSHW_5MM
IC4: XC9572XL; VQFP64
TCK: PTR1TP08R; TP08R
TDI: PTR1TP08R; TP08R
TDO: PTR1TP08R; TP08R
TMS: PTR1TP08R; TP08R
TP1, TP2, TP3, TP4, TP5: TPPAD1-13; P1-13
VR1: V_REG_LM1117SOT223; SOT223

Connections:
!CAS: IC4.15 (FB1MC9-I/O/GCK1); also elsewhere on the board
!CE_RAM: IC4.42 (FB3MC16); also elsewhere on the board
!RAS: IC4.4 (FB2MC12); also elsewhere on the board
!WE: IC4.2 (FB2MC11-I/O/GTS2); also elsewhere on the board
!WE_RAM: IC4.51 (FB4MC10); also elsewhere on the board
+3V3: 3V3.TP, C4.1.1, C4.2.1, C4.3.1, C4.4.1, C6.1, IC4.3 (VCCINT3,3V), IC4.26 (VCCIO2,5V/3,3V), IC4.37 (VCCINT3,3V), IC4.55 (VCCIO2,5V/3,3V), VR1.2 (OUT), VR1.4 (OUT)
BA0: IC4.22 (FB3MC2); also elsewhere on the board
BA1: IC4.25 (FB3MC8); also elsewhere on the board
BA2: IC4.31 (FB3MC3); also elsewhere on the board
BA3: IC4.33 (FB3MC11); also elsewhere on the board
BA4: IC4.35 (FB3MC14); also elsewhere on the board
BA5: IC4.39 (FB3MC10); also elsewhere on the board
BA6: IC4.43 (FB4MC2); also elsewhere on the board
BA7: IC4.46 (FB4MC3); also elsewhere on the board
BA8: IC4.48 (FB4MC11); also elsewhere on the board
BA9: IC4.47 (FB4MC4); also elsewhere on the board
BA10: IC4.44 (FB4MC5); also elsewhere on the board
BA11: IC4.45 (FB4MC8); also elsewhere on the board
BA12: IC4.49 (FB4MC6); also elsewhere on the board
BA13: IC4.50 (FB4MC14); also elsewhere on the board
BA14: IC4.52 (FB4MC12); also elsewhere on the board
BA15: IC4.58 (FB2MC3); also elsewhere on the board
BA16: IC4.57 (FB4MC17); also elsewhere on the board
BA17: IC4.56 (FB4MC15); also elsewhere on the board
BA18: IC4.59 (FB2MC4); also elsewhere on the board
BD0: IC4.20 (FB1MC17); also elsewhere on the board
BD1: IC4.19 (FB1MC15); also elsewhere on the board
BD2: IC4.18 (FB1MC10); also elsewhere on the board
BD3: IC4.17 (FB1MC14-I/O/GCK3); also elsewhere on the board
BD4: IC4.34 (FB3MC6); also elsewhere on the board
BD5: IC4.36 (FB3MC15); also elsewhere on the board
BD6: IC4.38 (FB3MC17); also elsewhere on the board
BD7: IC4.40 (FB3MC12); also elsewhere on the board
D0: IC4.64 (FB2MC9-I/O/GSR); also elsewhere on the board
D1: IC4.1 (FB2MC10); also elsewhere on the board
D2: IC4.13 (FB1MC4); also elsewhere on the board
D3: IC4.16 (FB1MC10-I/O/GCK2); also elsewhere on the board
D4: IC4.27 (FB3MC9); also elsewhere on the board
D5: IC4.24 (FB3MC5); also elsewhere on the board
D6: IC4.23 (FB1MC12); also elsewhere on the board
D7: IC4.32 (FB3MC4); also elsewhere on the board
GND: C1.2, C4.1.2, C4.2.2, C4.3.2, C4.4.2, C6.2, GND.TP, IC4.14 (GND), IC4.21 (GND), IC4.41 (GND), IC4.54 (GND), TP5.TP, VR1.1 (ADJ); also elsewhere on the board
MA0: IC4.12 (FB1MC3); also elsewhere on the board
MA1: IC4.11 (FB1MC8); also elsewhere on the board
MA2: IC4.10 (FB1MC6); also elsewhere on the board
MA3: IC4.9 (FB1MC5); also elsewhere on the board
MA4: IC4.7 (FB2MC17); also elsewhere on the board
MA5: IC4.6 (FB2MC15); also elsewhere on the board
MA6: IC4.5 (FB2MC14-I/O/GTS1); also elsewhere on the board
MA7: IC4.8 (FB1MC2); also elsewhere on the board
TCK: IC4.30 (TCK), TCK.TP
TDI: IC4.28 (TDI), TDI.TP
TDO: IC4.53 (TDO), TDO.TP
TMS: IC4.29 (TMS), TMS.TP
TP1: IC4.63 (FB2MC8), TP1.TP
TP2: IC4.62 (FB2MC6), TP2.TP
TP3: IC4.61 (FB2MC5), TP3.TP
TP4: IC4.60 (FB2MC2), TP4.TP
VCC: C1.1, VR1.3 (IN); also elsewhere on the board

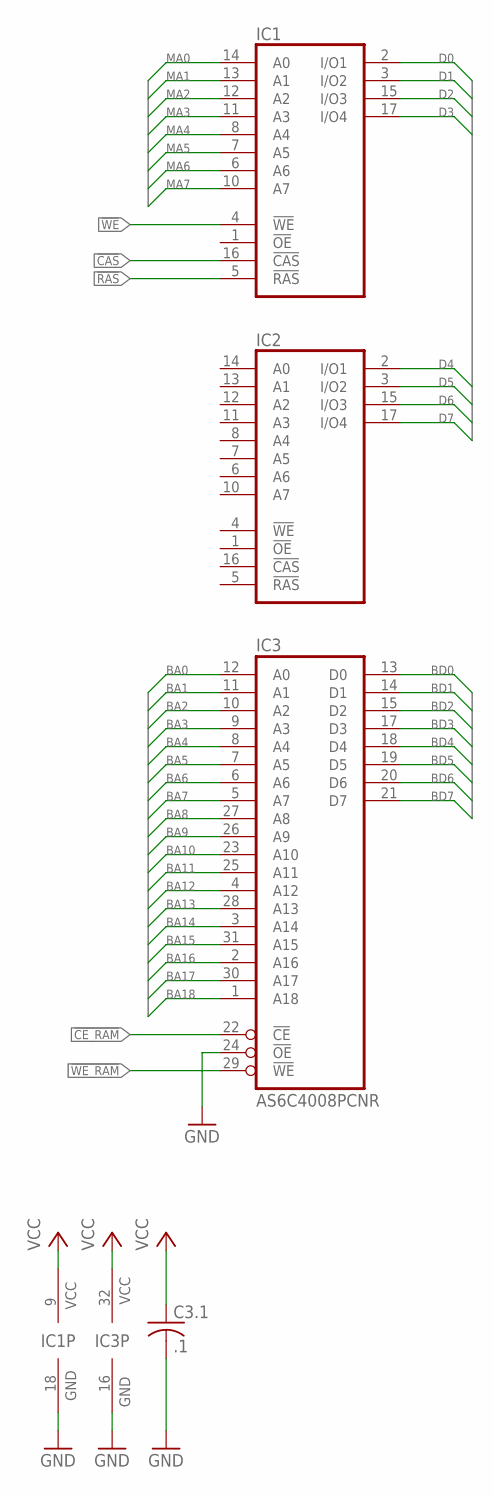
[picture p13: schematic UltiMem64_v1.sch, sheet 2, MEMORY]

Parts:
C3.1: .1; C0402
IC1, IC2: 41464C-HDR; DIL18_REV
IC3: AS6C4008PCNR; DIL32-RP

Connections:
!CAS: IC1.16 (!CAS); also elsewhere on the board
!CE_RAM: IC3.22 (!CE); also elsewhere on the board
!RAS: IC1.5 (!RAS); also elsewhere on the board
!WE: IC1.4 (!WE); also elsewhere on the board
!WE_RAM: IC3.29 (!WE); also elsewhere on the board
BA0: IC3.12 (A0); also elsewhere on the board
BA1: IC3.11 (A1); also elsewhere on the board
BA2: IC3.10 (A2); also elsewhere on the board
BA3: IC3.9 (A3); also elsewhere on the board
BA4: IC3.8 (A4); also elsewhere on the board
BA5: IC3.7 (A5); also elsewhere on the board
BA6: IC3.6 (A6); also elsewhere on the board
BA7: IC3.5 (A7); also elsewhere on the board
BA8: IC3.27 (A8); also elsewhere on the board
BA9: IC3.26 (A9); also elsewhere on the board
BA10: IC3.23 (A10); also elsewhere on the board
BA11: IC3.25 (A11); also elsewhere on the board
BA12: IC3.4 (A12); also elsewhere on the board
BA13: IC3.28 (A13); also elsewhere on the board
BA14: IC3.3 (A14); also elsewhere on the board
BA15: IC3.31 (A15); also elsewhere on the board
BA16: IC3.2 (A16); also elsewhere on the board
BA17: IC3.30 (A17); also elsewhere on the board
BA18: IC3.1 (A18); also elsewhere on the board
BD0: IC3.13 (D0); also elsewhere on the board
BD1: IC3.14 (D1); also elsewhere on the board
BD2: IC3.15 (D2); also elsewhere on the board
BD3: IC3.17 (D3); also elsewhere on the board
BD4: IC3.18 (D4); also elsewhere on the board
BD5: IC3.19 (D5); also elsewhere on the board
BD6: IC3.20 (D6); also elsewhere on the board
BD7: IC3.21 (D7); also elsewhere on the board
D0: IC1.2 (I/O1); also elsewhere on the board
D1: IC1.3 (I/O2); also elsewhere on the board
D2: IC1.15 (I/O3); also elsewhere on the board
D3: IC1.17 (I/O4); also elsewhere on the board
D4: IC2.2 (I/O1); also elsewhere on the board
D5: IC2.3 (I/O2); also elsewhere on the board
D6: IC2.15 (I/O3); also elsewhere on the board
D7: IC2.17 (I/O4); also elsewhere on the board
GND: C3.1.2, IC1.18 (GND), IC2.18 (GND), IC3.16 (GND), IC3.24 (!OE); also elsewhere on the board
MA0: IC1.14 (A0); also elsewhere on the board
MA1: IC1.13 (A1); also elsewhere on the board
MA2: IC1.12 (A2); also elsewhere on the board
MA3: IC1.11 (A3); also elsewhere on the board
MA4: IC1.8 (A4); also elsewhere on the board
MA5: IC1.7 (A5); also elsewhere on the board
MA6: IC1.6 (A6); also elsewhere on the board
MA7: IC1.10 (A7); also elsewhere on the board
VCC: C3.1.1, IC1.9 (VCC), IC2.9 (VCC), IC3.32 (VCC); also elsewhere on the board

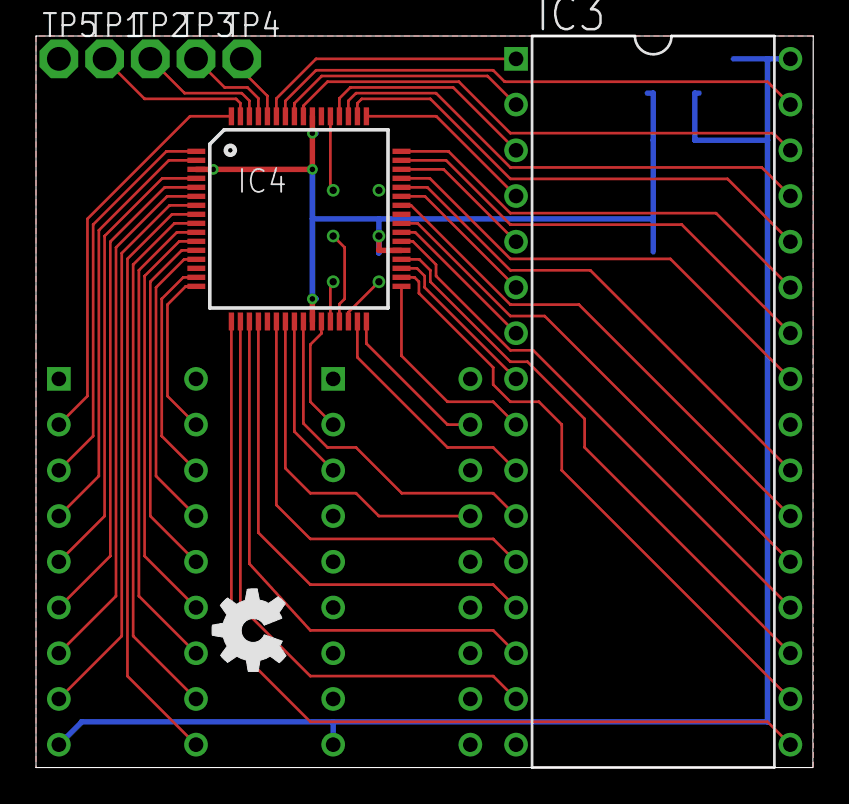
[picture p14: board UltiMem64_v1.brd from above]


Board: 2 copper layers, 43.2 x 40.6 mm, 24 parts (14 on the bottom side), 59 nets.

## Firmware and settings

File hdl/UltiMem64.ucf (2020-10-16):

#PACE: Start of Constraints generated by PACE

#PACE: Start of PACE I/O Pin Assignments
NET "_cas"  LOC = "P16"  ; 
NET "_ce_ram"  LOC = "P76"  ; 
NET "_ce_tag"  LOC = "p77"  ; 
NET "_lb"  LOC = "p74"  ; 
NET "_ras"  LOC = "P54"  ; 
NET "_reset"  LOC = "p27"  ;
NET "_ub"  LOC = "p72"  ; 
NET "_we"  LOC = "P56"  ; 
NET "_we_mem"  LOC = "P97"  ; 
NET "baddress<0>"  LOC = "P65"  ; 
NET "baddress<10>"  LOC = "P6"  ; 
NET "baddress<11>"  LOC = "P3"  ; 
NET "baddress<12>"  LOC = "P1"  ; 
NET "baddress<13>"  LOC = "P68"  ; 
NET "baddress<14>"  LOC = "P66"  ; 
NET "baddress<15>"  LOC = "P64"  ; 
NET "baddress<16>"  LOC = "P11"  ; 
NET "baddress<17>"  LOC = "P9"  ; 
NET "baddress<18>"  LOC = "P12"  ; 
NET "baddress<19>"  LOC = "p61"  ; 
NET "baddress<1>"  LOC = "P67"  ; 
NET "baddress<20>"  LOC = "p13"  ; 
NET "baddress<2>"  LOC = "P70"  ; 
NET "baddress<3>"  LOC = "P71"  ; 
NET "baddress<4>"  LOC = "P73"  ; 
NET "baddress<5>"  LOC = "P99"  ; 
NET "baddress<6>"  LOC = "P2"  ; 
NET "baddress<7>"  LOC = "P4"  ; 
NET "baddress<8>"  LOC = "P7"  ; 
NET "baddress<9>"  LOC = "P8"  ; 
NET "bdata<0>"  LOC = "P79"  ; 
NET "bdata<10>"  LOC = "p92"  ; 
NET "bdata<11>"  LOC = "p90"  ; 
NET "bdata<12>"  LOC = "p86"  ; 
NET "bdata<13>"  LOC = "p82"  ; 
NET "bdata<14>"  LOC = "p80"  ; 
NET "bdata<15>"  LOC = "p78"  ; 
NET "bdata<1>"  LOC = "P81"  ; 
NET "bdata<2>"  LOC = "P85"  ; 
NET "bdata<3>"  LOC = "P87"  ; 
NET "bdata<4>"  LOC = "P89"  ; 
NET "bdata<5>"  LOC = "P91"  ; 
NET "bdata<6>"  LOC = "P93"  ; 
NET "bdata<7>"  LOC = "P95"  ; 
NET "bdata<8>"  LOC = "p96"  ; 
NET "bdata<9>"  LOC = "p94"  ; 
NET "clock"  LOC = "P22"  ; 
NET "data<0>"  LOC = "P60"  ; 
NET "data<1>"  LOC = "P59"  ; 
NET "data<2>"  LOC = "P46"  ; 
NET "data<3>"  LOC = "P43"  ; 
NET "data<4>"  LOC = "P29"  ; 
NET "data<5>"  LOC = "P30"  ; 
NET "data<6>"  LOC = "P17"  ; 
NET "data<7>"  LOC = "P15"  ; 
NET "maddress<0>"  LOC = "P55"  ; 
NET "maddress<1>"  LOC = "P19"  ; 
NET "maddress<2>"  LOC = "P18"  ; 
NET "maddress<3>"  LOC = "P14"  ; 
NET "maddress<4>"  LOC = "P63"  ; 
NET "maddress<5>"  LOC = "P58"  ; 
NET "maddress<6>"  LOC = "P20"  ; 
NET "maddress<7>"  LOC = "P10"  ; 
#NET "test<1>"  LOC = "p50"  ; 
#NET "test<2>"  LOC = "p49"  ; 
#NET "test<3>"  LOC = "p42"  ; 
#NET "test<4>"  LOC = "p41"  ; 
#NET "test<5>"  LOC = "p33"  ; 
#NET "test<6>"  LOC = "p32"  ; 
#NET "test<7>"  LOC = "p28"  ; 

#PACE: Start of PACE Area Constraints

#PACE: Start of PACE Prohibit Constraints

#PACE: End of Constraints generated by PACE

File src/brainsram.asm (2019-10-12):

 if 0
http://sid.fi/~tnt/tmp/brainsram.zip

$c000
	bit 7 is mmu regs visible
		(1 = on, and if set to 0, it will disappear,
		and I don't have a way to turn it back on yet).
	bit 0 is mmu enabled
$c001
	8 bit mapping set to view in $c01x (0-255)
$c002
	8 bit mapping to use (0-255)


each mapping set is 16 bytes, and each mapping is 1 byte 0-255 that
tells what 4kB page in the first 1MB  to use for that 4kB space in RAM
(slot #0 is $000-$0fff, 1 = 1xxx, 2 = 2xxx, etc.)

 endif


	processor	6502

MMU	= $c000
MMU_VISIBLE	= $80
MMU_ENABLED	= $81

	seg.u	zp
	org	$fb
ptr	ds.w	1
delta	ds.b	1



	seg	code

	org	$0801

;	BASIC stub "SYS2061"
	dc.w	.link
	dc.w	2019
	HEX	9e 32 30 36 31 00
.link	dc.w	0


START

;	we don't want interference from interrupts or VIC-II

	sei
	lda	#0
	sta	$d011
	sta	$d015
	JSR	WaitRast


;	make MMU visible, do NOT activate it yet so we are safe no matter what the mapping is

	lda	#MMU_VISIBLE
	sta	MMU

;	make mapping set #0 visible and use it

	lda	#0
	sta	MMU+1
	sta	MMU+2

;	map the first 64 KB of SRAM to C64 memory

	ldx	#$0f
.init	txa
	sta	MMU+$10,x
	dex
	bpl	.init

;	enable MMU

	lda	#MMU_VISIBLE|MMU_ENABLED
	sta	MMU






;	now test memory banks 1-255 at $1000

TESTMEM

	ldx	#1		; bank number in X

.test1	stx	$d020		; show that we are working
	stx	MMU+$11

	jsr	StartTest
.floop	txa			; fill one page with arithmetic sequence, starting with page number
.fill	sta	(ptr),y
	cmp	(ptr),y		; quick test for stuck-at and transition faults
	bne	.error1
	eor	#$ff
	sta	(ptr),y
	cmp	(ptr),y
	bne	.error1
	eor	#$ff
	sta	(ptr),y
	cmp	(ptr),y
	bne	.error1

	clc
	adc	delta
	iny
	bne	.fill
	jsr	ChangePage
	bcc	.floop

;	see if we read the same values back - limited address decoder fault test

	jsr	StartTest
.cloop	txa
.cmp	cmp	(ptr),y
	bne	.error1
	clc
	adc	delta
	iny
	bne	.cmp
	jsr	ChangePage
	bcc	.cloop

	inx			; repeat until 255 pages done
	bne	.test1


;	now read all banks again to test for crosstalk between banks

	ldx	#1

.test2	stx	$d020
	stx	MMU+$11
	;stx	MMU+1

	jsr	StartTest
.xloop	txa			; fill one page with arithmetic sequence, starting with page number
.xcmp	cmp	(ptr),y
	bne	.error2
	clc
	adc	delta
	iny
	bne	.xcmp
	jsr	ChangePage
	bcc	.xloop

	inx			; repeat until 255 pages done
	bne	.test2


;	test complete, show green screen for five seconds

	lda	#5
	sta	$d020
	ldx	#250
.delay	jsr	WaitRast
	dex
	bne	.delay

	jmp	TESTMEM		; repeat ad infinitum




;	memory error inside 4 KB block

.error1	lda	#$e1
	dc.b	$2c
.error2	lda	#$e2

	ldy	#$1b
	sty	$d011

	jsr	.prhex
	lda	#$20
	jsr	$ffd2
	txa
	jsr	.prhex
	lda	#$20
	jsr	$ffd2
	lda	$1000
	jsr	.prhex
	lda	#$0d
	jmp	$ffd2

.prhex	pha
	lsr
	lsr
	lsr
	lsr
	jsr	.prn
	pla
.prn	and	#$0f
	ora	#$30
	cmp	#$3a
	bcc	.num
	adc	#6
.num	jmp	$ffd2


StartTest
	lda	#1
	sta	delta

	lda	#>$1000
	ldy	#<$1000
	sty	ptr
	sta	ptr+1
	rts

ChangePage
	inc	delta		; increment common difference
	inc	ptr+1
	lda	ptr+1
	cmp	#>$2000
	rts

WaitRast
	bit	$d011
	bpl	*-3
	bit	$d011
	bmi	*-3
	rts

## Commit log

2019-09-22 Rev 2
    [UltiMem64_v2.brd, UltiMem64_v2.sch]
2020-10-16 Added Color RAM functionality
    [UltiMem64_Color.brd, UltiMem64_Color.sch]
2021-01-28 UltiColorMEM RAM Design
    [UltiMem64_Color_CPLD.brd, UltiMem64_Color_CPLD.sch]

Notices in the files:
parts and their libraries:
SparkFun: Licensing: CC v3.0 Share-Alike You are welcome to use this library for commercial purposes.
